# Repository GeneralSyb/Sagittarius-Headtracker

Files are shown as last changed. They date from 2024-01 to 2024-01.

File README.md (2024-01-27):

These are the project files for the Sagittarius wireless headtracker.

A bit of background:
This project started off as a way to find a cheap high performance headtracker, but it didn't take me long to find out that a cheap and simple wireless headtracker would be more suited for my needs.
I started off with some cheap IMU modules and an ESP32, however most of these sensors were fakes because the real ones weren't in production anymore. They worked, but they had issues with drift and low dynamic accuracy.
The first prototype that actually worked well used a BNO085 sensor breakout board from Adafruit and an ESP32-S2 Wemos board to process and transmit the data over WiFi to Opentrack that was using the UDP input.

Do not that everything you will find here is not a complete and ready to go device you can just build. Knowledge about electronics, embedded software and hardware design is REQUIRED to get anything out of this. After all, this more of a dump of my knowledge, findings and what I've made than a complete project.
The following thins might be of interest if you are looking to make something like this:
- PCB Schematics
- Sagittarius S1 Firmware
  - Data transmit function (packet construction)
  - Quaternion processing

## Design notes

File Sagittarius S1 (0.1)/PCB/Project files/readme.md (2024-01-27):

Please refer to the PCB schematic PDF to get any sort of information about the S1 V0.1 prototype. The PCB design is flawed and rushed, isn't even complete and shouldn't be considered as something that you should make.

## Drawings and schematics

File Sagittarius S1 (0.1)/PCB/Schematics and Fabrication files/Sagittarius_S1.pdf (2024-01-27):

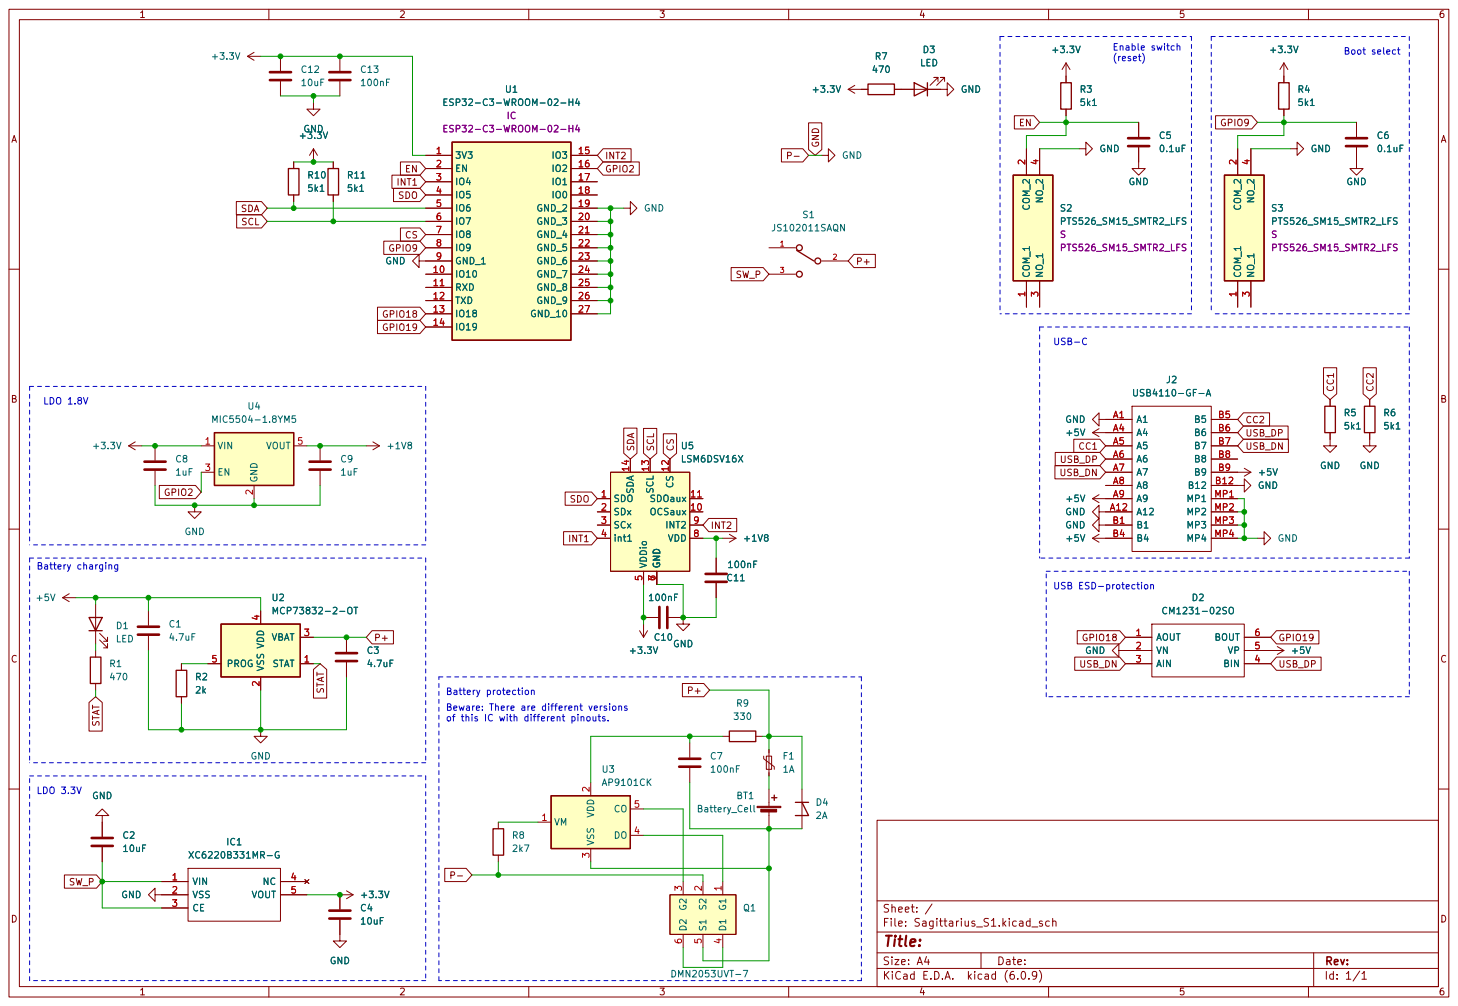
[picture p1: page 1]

3 DO 4 CO 5 U3AP9101CK GND STAT P- CC1

Battery protection
Beware: There are different versions of this IC with different pinouts.

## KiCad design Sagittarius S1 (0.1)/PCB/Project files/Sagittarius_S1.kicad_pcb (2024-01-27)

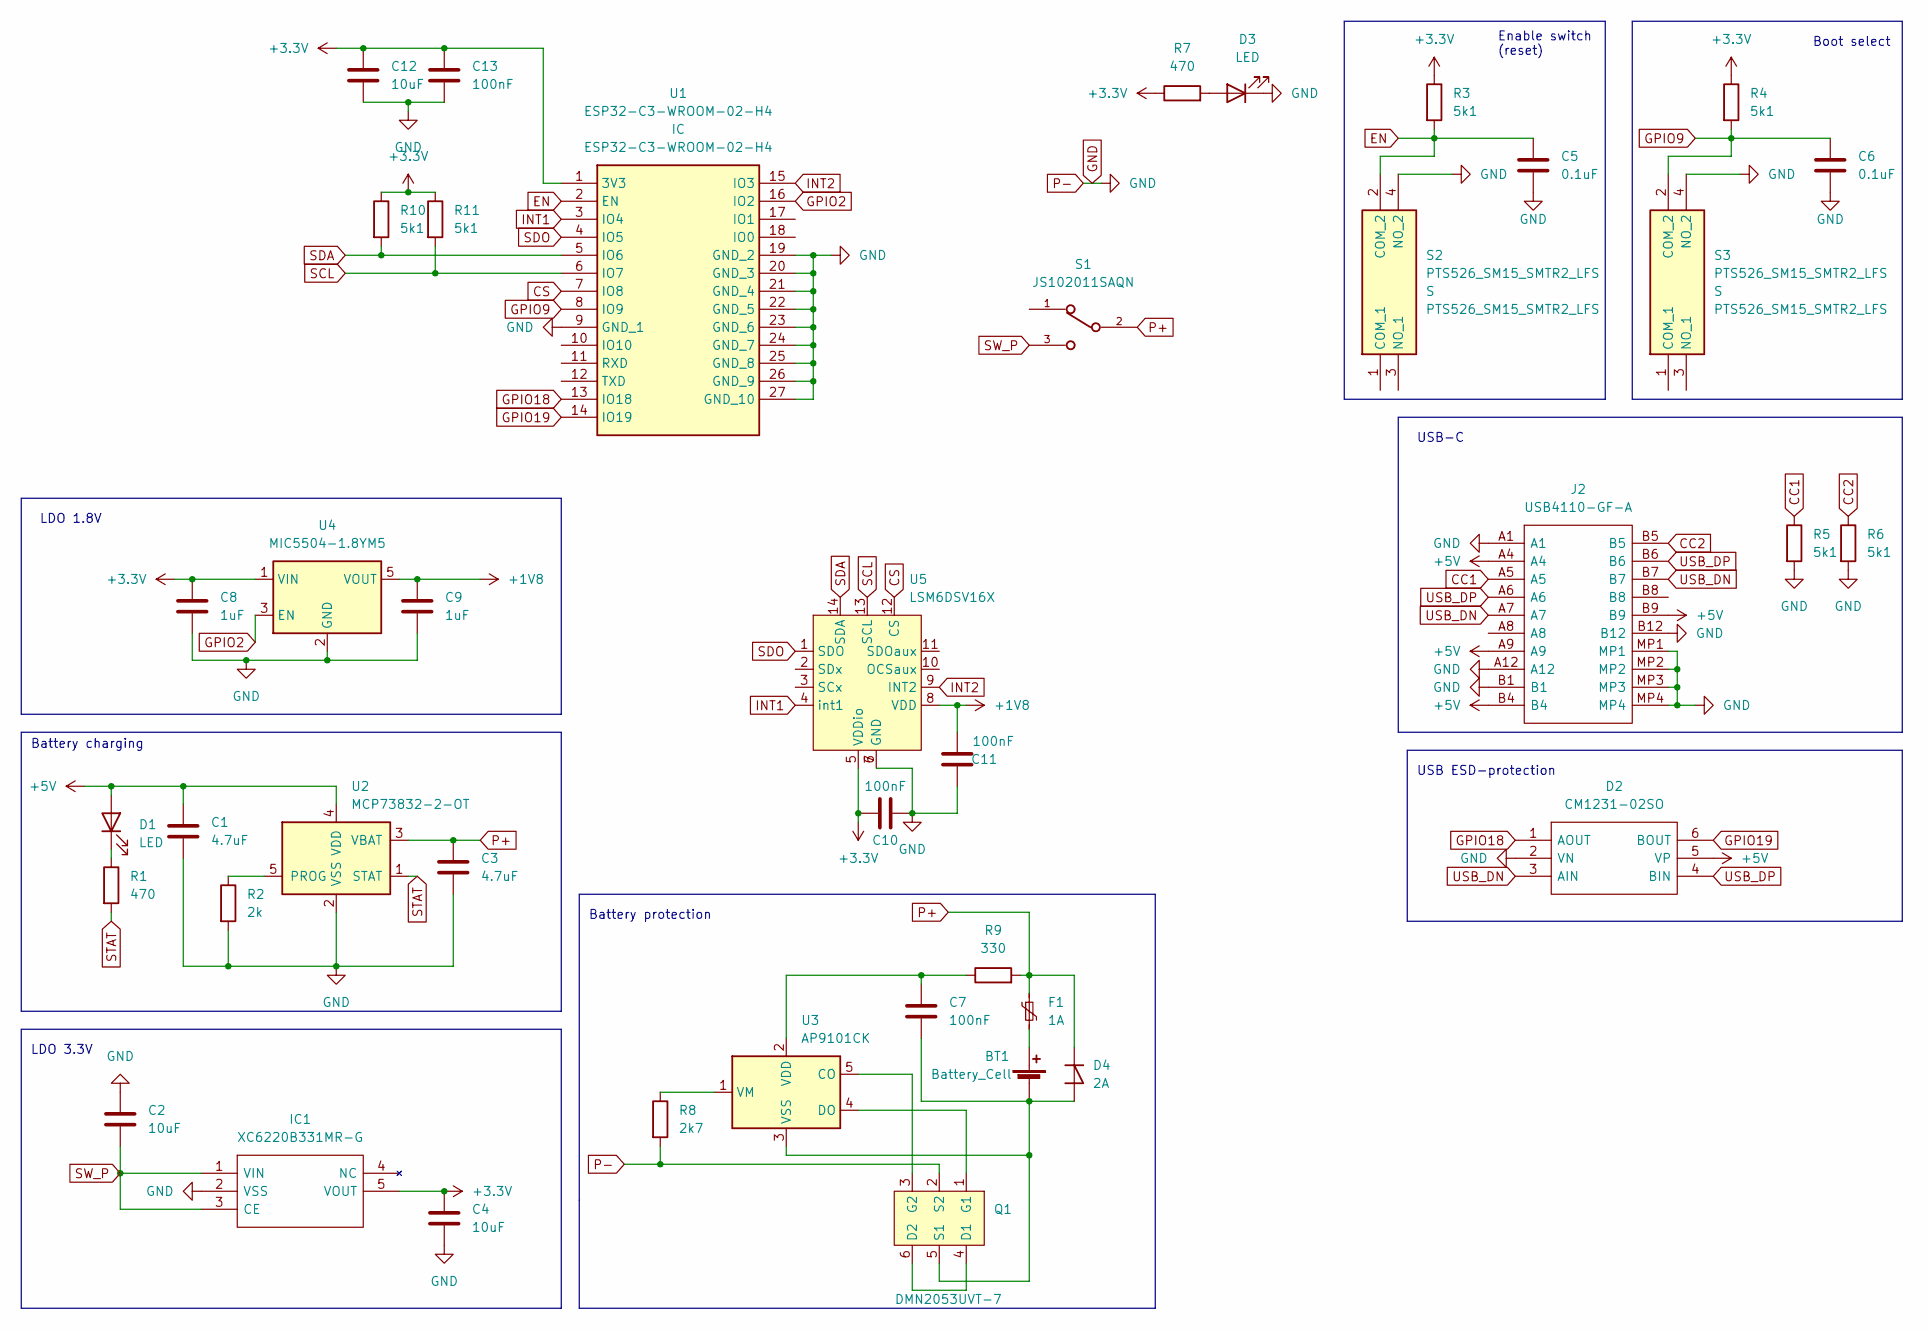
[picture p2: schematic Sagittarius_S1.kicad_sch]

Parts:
BT1: Battery_Cell; BatteryHolder_Keystone_1042_1x18650
C1, C3: 4.7uF; C_0402_1005Metric
C2, C4, C12: 10uF; C_0402_1005Metric
C5, C6: 0.1uF; C_0402_1005Metric
C7, C10, C11, C13: 100nF; C_0402_1005Metric
C8, C9: 1uF; C_0402_1005Metric
D1, D3: LED; LED_0603_1608Metric
D2: CM1231-02SO; SOT95P280X145-6N; Mouser Part Number 748-CM1231-02SO
D4: 2A; D_SOD-123F
F1: 1A; Fuse_1812_4532Metric_Pad1.30x3.40mm_HandSolder
IC1: XC6220B331MR-G; SOT95P280X130-5N; Mouser Part Number 865-XC6220B331MR-G
J2: USB4110-GF-A; USB4110GFA; Mouser Part Number 640-USB4110-GF-A
Q1: DMN2053UVT-7; SOT-23-6
R1, R7: 470; R_0402_1005Metric
R2: 2k; R_0402_1005Metric
R3, R4, R5, R6, R10, R11: 5k1; R_0402_1005Metric
R8: 2k7; R_0402_1005Metric
R9: 330; R_0402_1005Metric
S1: JS102011SAQN; SW_JS102011SAQN
S2, S3: PTS526_SM15_SMTR2_LFS; PTS526SM15SMTR2LFS; Mouser Part Number 611-PTS526SM15SMTR2L
U1: ESP32-C3-WROOM-02-H4; ESP32C3WROOM02H4; Mouser Part Number 356-ESP32C3WROOM02H4
U2: MCP73832-2-OT; SOT-23-5
U3: AP9101CK; SOT-23-5
U4: MIC5504-1.8YM5; SOT-23-5
U5: LSM6DSV16X; LGA-14L 2.5 x 3.0

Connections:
+1V8: C9.1, C11.1, U4.5 (VOUT), U5.8 (VDD)
+3.3V: C4.1, C8.1, C10.2, C12.1, C13.1, IC1.5 (VOUT), R3.1, R4.1, R7.1, R10.1, R11.1, U1.1 (3V3), U4.1 (VIN), U5.5 (VDDio)
+5V: C1.2, D1.2 (A), D2.5 (VP), J2.A4, J2.A9, J2.B4, J2.B9, U2.4 (VDD)
CC1: J2.A5, R5.1
CC2: J2.B5, R6.1
CS: U1.7 (IO8), U5.12 (CS)
EN: C5.1, R3.2, S2.2 (COM_2), U1.2 (EN)
GND: C1.1, C2.1, C3.1, C4.2, C5.2, C6.2, C8.2, C9.2, C10.1, C11.2, C12.2, C13.2, D2.2 (VN), D3.1 (K), IC1.2 (VSS), J2.A1, J2.A12, J2.B1, J2.B12, J2.MP1, J2.MP2, J2.MP3, J2.MP4, Q1.2 (S2), R2.2, R5.2, R6.2, R8.2, S2.4 (NO_2), S3.4 (NO_2), U1.9 (GND_1), U1.19 (GND_2), U1.20 (GND_3), U1.21 (GND_4), U1.22 (GND_5), U1.23 (GND_6), U1.24 (GND_7), U1.25 (GND_8), U1.26 (GND_9), U1.27 (GND_10), U2.2 (VSS), U4.2 (GND), U5.6 (GND), U5.7 (GND)
GPIO2: U1.16 (IO2), U4.3 (EN)
GPIO9: C6.1, R4.2, S3.2 (COM_2), U1.8 (IO9)
GPIO18: D2.1 (AOUT), U1.13 (IO18)
GPIO19: D2.6 (BOUT), U1.14 (IO19)
INT1: U1.3 (IO4), U5.4 (int1)
INT2: U1.15 (IO3), U5.9 (INT2)
unnamed: BT1.1 (+), F1.2
unnamed: BT1.2 (-), C7.2, D4.2 (A), Q1.5 (S1), U3.3 (VSS)
unnamed: C7.1, R9.1, U3.2 (VDD)
unnamed: D1.1 (K), R1.1
unnamed: D3.2 (A), R7.2
unnamed: Q1.1 (G1), U3.4 (DO)
unnamed: Q1.3 (G2), U3.5 (CO)
unnamed: Q1.4 (D1), Q1.6 (D2)
unnamed: R2.1, U2.5 (PROG)
unnamed: R8.1, U3.1 (VM)
P+: C3.2, D4.1 (K), F1.1, R9.2, S1.2, U2.3 (VBAT)
SCL: R11.2, U1.6 (IO7), U5.13 (SCL)
SDA: R10.2, U1.5 (IO6), U5.14 (SDA)
SDO: U1.4 (IO5), U5.1 (SDO)
STAT: R1.2, U2.1 (STAT)
SW_P: C2.2, IC1.1 (VIN), IC1.3 (CE), S1.3
USB_DN: D2.3 (AIN), J2.A7, J2.B7
USB_DP: D2.4 (BIN), J2.A6, J2.B6

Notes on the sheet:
Boot select
Battery protection
LDO 1.8V
USB-C
Battery charging
LDO 3.3V
Enable switch (reset)
USB ESD-protection

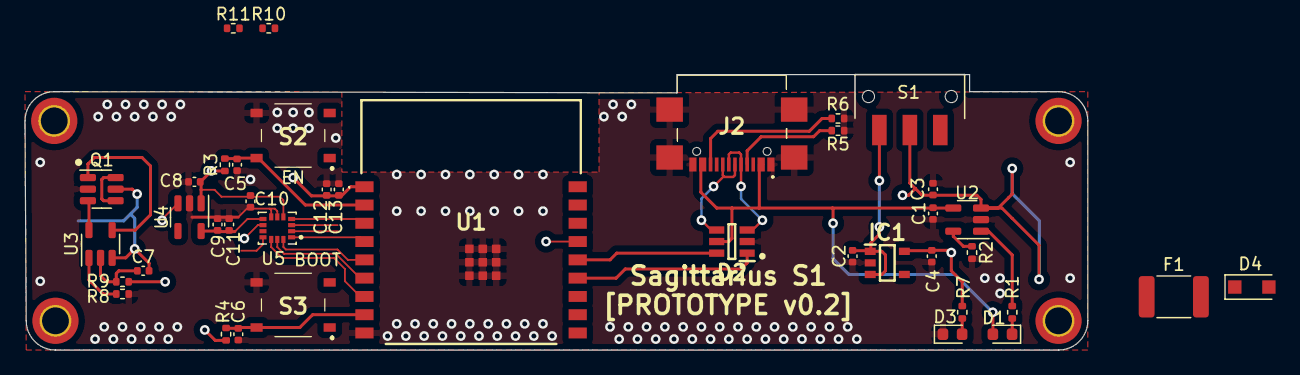
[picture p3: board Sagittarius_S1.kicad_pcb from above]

Board: 4 copper layers, 87.2 x 22.6 mm, 41 parts (1 on the bottom side), 32 nets.

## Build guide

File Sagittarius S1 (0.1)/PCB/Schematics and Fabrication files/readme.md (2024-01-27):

The only thing that isn't completely flawed about the S1 V0.1 prototype is the schematic itself. Most of what you will find here can be used for other devices or be roughly based upon it. Fabrication files are not of any relevance because the PCB I designed doesn't work as intented so should not be made.

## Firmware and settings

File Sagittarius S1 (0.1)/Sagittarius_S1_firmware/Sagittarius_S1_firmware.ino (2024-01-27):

/*
   @file    LSM6DSV16X_Sensor_Fusion.ino
   @author  STMicroelectronics
   @brief   Example to use the LSM6DSV16X library with Sensor Fusion Low Power.
 *******************************************************************************
   Copyright (c) 2022, STMicroelectronics
   All rights reserved.

   This software component is licensed by ST under BSD 3-Clause license,
   the "License"; You may not use this file except in compliance with the
   License. You may obtain a copy of the License at:
                          opensource.org/licenses/BSD-3-Clause

 *******************************************************************************
*/

/*
 * You can display the quaternion values with a 3D model connecting for example to this link:
 * https://adafruit.github.io/Adafruit_WebSerial_3DModelViewer/
 */

#include <LSM6DSV16XSensor.h>
#include <Wire.h>

#include <WiFi.h>
#include <WiFiUdp.h>

#define CS 8
#define SCL 7
#define SDA 6
#define EN 2
#define AS 5

#define ALGO_FREQ  120U /* Algorithm frequency 120Hz */
#define ALGO_PERIOD  (1000U / ALGO_FREQ) /* Algorithm period [ms] */
unsigned long startTime, elapsedTime;

LSM6DSV16XSensor AccGyr(&Wire);
uint8_t status = 0;
uint32_t k = 0;

uint8_t tag = 0;
float quaternions[4] = {0};

struct data {
  double positionX = 0.0;
  double positionY = 0.0;
  double positionZ = 0.0;
  double rotationX = 0.0;
  double rotationY = 0.0;
  double rotationZ = 0.0;
} data;

struct euler_t {
  float yaw;
  float pitch;
  float roll;
} ypr;

float currentYaw, currentPitch, currentRoll;
float lastPitch = 0.00, lastYaw = 0.00, lastRoll = 0.00;

//---------------------------------------

// WiFi network name and password:
const char * networkName = "SSID";
const char * networkPswd = "Password";

//IP address to send UDP data to:
// either use the ip address of the server or 
// a network broadcast address
const char * udpAddress = "target computer IP";
const int udpPort = 4747;

//Are we currently connected?
boolean connected = false;

//The udp library class
WiFiUDP udp;

unsigned long startup;
bool started = false;

void setup()
{
  // Set up pins
  pinMode(CS, OUTPUT); // Chip Select pin on IMU is used to enable I2C
  pinMode(EN, OUTPUT); // EN pin on 1.8V LDO, used to turn on the IMU after the pins have been set correctly
  pinMode(AS, OUTPUT); // Address Select, HIGH = least significant bit of the 7-bit address is 1 (0x6b), LOW = 0 (0x6a). Connects to the SDO pin on the IMU.

  digitalWrite(CS, HIGH); // Turn on I2C
  digitalWrite(AS, HIGH); // Set address to 0x6b
  digitalWrite(EN, HIGH); // Turn on IMU

  delay(50);

  //Serial.begin(115200);

  delay(500);

  //WiFi setup
  //Serial.println("Connecting to network");
  //Connect to the WiFi network
  connectToWiFi(networkName, networkPswd);

  //Serial.println("Starting I2C");
  Wire.begin(SDA, SCL);

  //Serial.println("Starting IMU");
  // Initialize LSM6DSV16X.
  AccGyr.begin();

  //Serial.println("Enabling SFLP");
  // Enable Sensor Fusion
  status |= AccGyr.Enable_Rotation_Vector();

  if (status != LSM6DSV16X_OK) {
    //Serial.println("LSM6DSV16X Sensor failed to init/configure");
    while (1);
  }
  //Serial.println("LSM6DSV16X SFLP Demo");

  startup = millis();
}

void loop()
{
  uint16_t fifo_samples;
  // Get start time of loop cycle
  startTime = millis();

  // Check the number of samples inside FIFO
  if (AccGyr.FIFO_Get_Num_Samples(&fifo_samples) != LSM6DSV16X_OK) {
    //Serial.println("LSM6DSV16X Sensor failed to get number of samples inside FIFO");
    while (1);
  }

  // Read the FIFO if there is one stored sample
  if (fifo_samples > 0) {
    for (int i = 0; i < fifo_samples; i++) {
      //Serial.println("Checking FIFO tag");
      AccGyr.FIFO_Get_Tag(&tag);
      if (tag == 0x13u) {
        //Serial.println("Getting quaternions");
        AccGyr.FIFO_Get_Rotation_Vector(&quaternions[0]);

        // Print Quaternion data
        /*Serial.print("Quaternion: ");
        Serial.print(quaternions[3], 4);
        Serial.print(", ");
        Serial.print(quaternions[0], 4);
        Serial.print(", ");
        Serial.print(quaternions[1], 4);
        Serial.print(", ");
        Serial.println(quaternions[2], 4);*/

        data.rotationX = currentYaw;
        data.rotationY = currentPitch;
        data.rotationZ = currentRoll;

        uint8_t ByteArray[sizeof(data)];
        memcpy(ByteArray, &data, sizeof(data));
        for (int i = 0; i<sizeof(ByteArray); i++) {
          Serial.print(ByteArray[i], HEX);
        }
        Serial.println();

        quaternionToEuler(quaternions[3], quaternions[0], quaternions[1], quaternions[2]);

        udp.beginPacket(udpAddress,udpPort);
        udp.write(ByteArray, sizeof(ByteArray));
        udp.endPacket();

        // Compute the elapsed time within loop cycle and wait
        elapsedTime = millis() - startTime;

        if ((long)(ALGO_PERIOD - elapsedTime) > 0) {
          delay(ALGO_PERIOD - elapsedTime);
        }

        /*if (millis() - startup > 10000 && !started) {
          currentPitch = 0;
          currentYaw = 0;
          currentRoll = 0;
          lastPitch = 0;
          lastYaw = 0;
          lastRoll = 0;
          started = true;
          Serial.println("Homing...");
        }*/
      }
    }
  }
}

void quaternionToEuler(float qr, float qi, float qj, float qk) {

    float sqr = sq(qr);
    float sqi = sq(qi);
    float sqj = sq(qj);
    float sqk = sq(qk);

    float pitch = atan2(2.0 * (qi * qj + qk * qr), (sqi - sqj - sqk + sqr));
    float roll = asin(-2.0 * (qi * qk - qj * qr) / (sqi + sqj + sqk + sqr));
    float yaw = atan2(2.0 * (qj * qk + qi * qr), (-sqi - sqj + sqk + sqr));

    pitch *= RAD_TO_DEG;
    roll *= RAD_TO_DEG;
    yaw *= RAD_TO_DEG;

    float dPitch = pitch - lastPitch;
    float dRoll = roll - lastRoll;
    float dYaw = yaw - lastYaw;

    dPitch = fmod(dPitch + 540, 360) -180;
    dRoll = fmod(dRoll + 540, 360) -180;
    dYaw = fmod(dYaw + 540, 360) -180;

    currentPitch += dPitch;
    currentRoll += dRoll;
    currentYaw += dYaw;

    //Serial.print("Pitch out: "); Serial.print(currentPitch); Serial.print("  dPitch: "); Serial.print(dPitch, 5); Serial.print("  lastPitch: "); Serial.print(lastPitch); Serial.print("  currentPitch: "); Serial.println(pitch);

    lastPitch = pitch;
    lastRoll = roll;
    lastYaw = yaw;
}

void connectToWiFi(const char * ssid, const char * pwd){
  //Serial.println("Connecting to WiFi network: " + String(ssid));

  // delete old config
  WiFi.disconnect(true);
  //register event handler
  WiFi.onEvent(WiFiEvent);
  
  //Initiate connection
  WiFi.begin(ssid, pwd);

  //Serial.println("Waiting for WIFI connection...");
}

//wifi event handler
void WiFiEvent(WiFiEvent_t event){
    switch(event) {
      case ARDUINO_EVENT_WIFI_STA_GOT_IP:
          //When connected set 
          //Serial.print("WiFi connected! IP address: ");
          //Serial.println(WiFi.localIP());  
          //initializes the UDP state
          //This initializes the transfer buffer
          udp.begin(WiFi.localIP(),udpPort);
          connected = true;
          break;
      case ARDUINO_EVENT_WIFI_STA_DISCONNECTED:
          //Serial.println("WiFi lost connection");
          connected = false;
          break;
      default: break;
    }
}
